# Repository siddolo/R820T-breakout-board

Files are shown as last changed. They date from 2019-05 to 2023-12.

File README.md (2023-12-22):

# Rafael Micro R820 Breakout Board

A simple radio front-end for rapid prototyping purposes. It implements the minimum circuit needed by the R820T chip, exposing the I2C bus, the IF output, and the ACG control of the tuner.

R820T KiCad library: https://github.com/siddolo/kicad-library

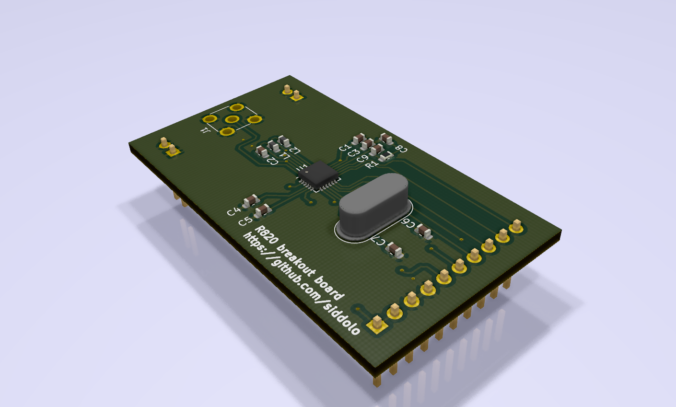
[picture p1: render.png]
R820 Breakout Board




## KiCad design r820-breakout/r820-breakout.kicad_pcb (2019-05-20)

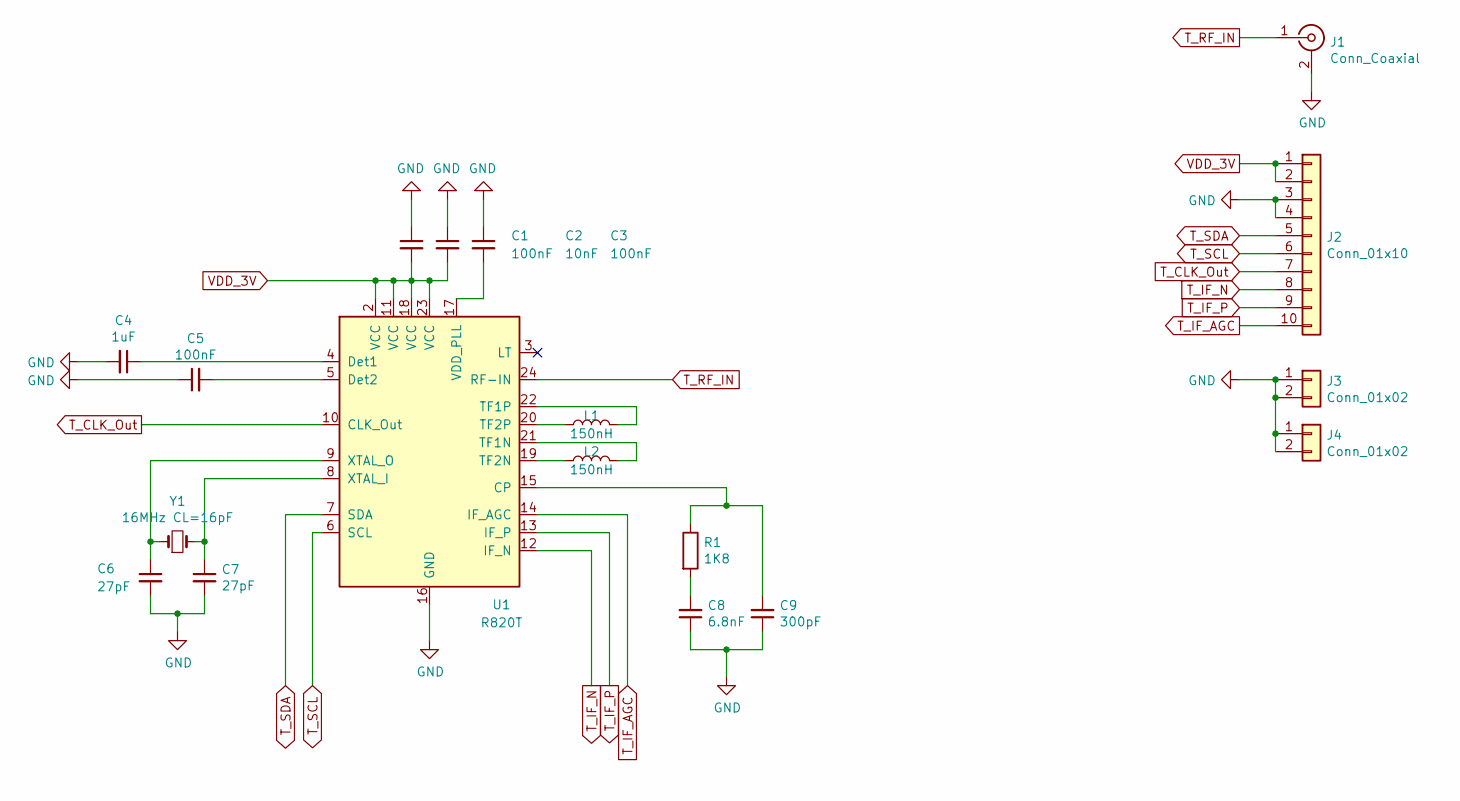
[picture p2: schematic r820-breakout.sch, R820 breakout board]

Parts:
C1, C3, C5: 100nF; C_0603_1608Metric
C2: 10nF; C_0603_1608Metric
C4: 1uF; C_0603_1608Metric
C6, C7: 27pF; C_0603_1608Metric
C8: 6.8nF; C_0603_1608Metric
C9: 300pF; C_0603_1608Metric
J1: Conn_Coaxial; SMA_Molex_73251-2200_Horizontal
J2: Conn_01x10; PinHeader_1x10_P2.54mm_Vertical
J3, J4: Conn_01x02; PinHeader_1x02_P2.54mm_Vertical
L1, L2: 150nH; L_0603_1608Metric
R1: 1K8; R_0603_1608Metric
U1: R820T; InvenSense_QFN-24_4x4mm_P0.5mm
Y1: 16MHz CL=16pF; Crystal_HC49-4H_Vertical

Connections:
GND: C1.1, C2.1, C3.1, C4.2, C5.1, C6.2, C7.2, C8.1, C9.1, J1.2 (Ext), J2.3, J2.4, J3.1, J3.2, J4.1, J4.2, U1.16 (GND)
unnamed: C3.2, U1.17 (VDD_PLL)
unnamed: C4.1, U1.4 (Det1)
unnamed: C5.2, U1.5 (Det2)
unnamed: C6.1, U1.9 (XTAL_O), Y1.1
unnamed: C7.1, U1.8 (XTAL_I), Y1.2
unnamed: C8.2, R1.2
unnamed: C9.2, R1.1, U1.15 (CP)
unnamed: L1.1, U1.20 (TF2P)
unnamed: L1.2, U1.22 (TF1P)
unnamed: L2.1, U1.19 (TF2N)
unnamed: L2.2, U1.21 (TF1N)
T_CLK_Out: J2.7, U1.10 (CLK_Out)
T_IF_AGC: J2.10, U1.14 (IF_AGC)
T_IF_N: J2.8, U1.12 (IF_N)
T_IF_P: J2.9, U1.13 (IF_P)
T_RF_IN: J1.1 (In), U1.24 (RF-IN)
T_SCL: J2.6, U1.6 (SCL)
T_SDA: J2.5, U1.7 (SDA)
VDD_3V: C1.2, C2.2, J2.1, J2.2, U1.2 (VCC), U1.11 (VCC), U1.18 (VCC), U1.23 (VCC)

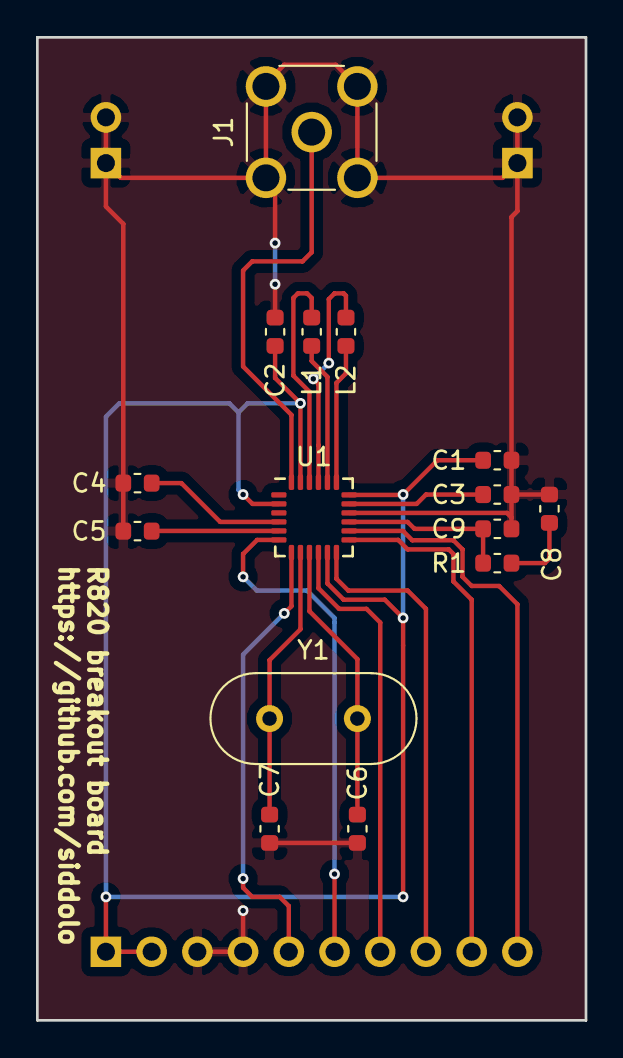
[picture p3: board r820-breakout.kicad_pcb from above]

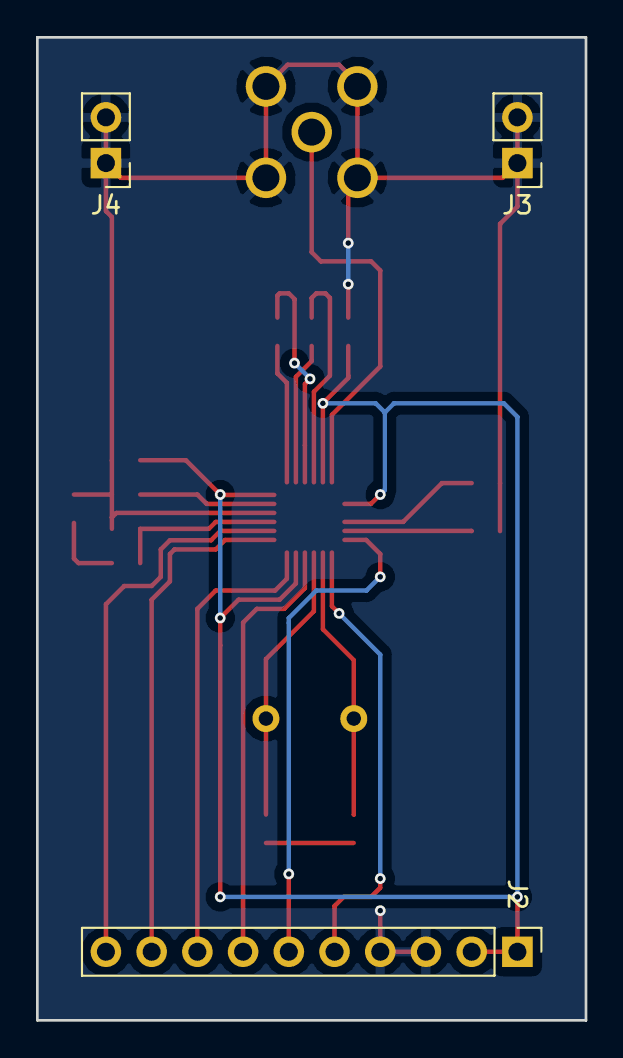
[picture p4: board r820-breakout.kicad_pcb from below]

Board: 2 copper layers, 30.5 x 54.6 mm, 18 parts (3 on the bottom side), 20 nets.

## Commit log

2019-05-19 R820T breakout board
    [r820-breakout.kicad_pcb, r820-breakout.sch]
2019-05-20 add dimension
    [r820-breakout.kicad_pcb]
2019-05-20 added KiCad library reference
